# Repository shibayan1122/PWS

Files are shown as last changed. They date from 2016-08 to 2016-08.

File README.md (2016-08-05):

# PWS(Personal Wireless Studio)

---
Maker Faire Tokyo 2016 <http://makezine.jp/event/mft2016/> のヤマハ(株)ブースにて展示を行った、ギター向けIoTデバイス(PWS: Personal Wireless Studio)のハードウェア開発資料・ソフトウェア一式を公開しています。  
PWS の制作方法に関しては、Fabble のプロジェクトページ <http://fabble.cc/yamahafsm/craft-iot-guitar> をご参照下さい。

## ディレクトリ
### hardware
パネル基板の設計図、部品表などを公開しています。

### software
PWS を動作させるのに必要なソフトウェア一式を公開しています。

## 著作権とライセンス
**Copyright (c) 2016 Yamaha Corporation released under the MIT license.**  
このソフトウェアは、MITライセンスのもとで公開しています。詳しくは LICENSE をご参照ください。  
(This software is released under the MIT License, see LICENSE.)

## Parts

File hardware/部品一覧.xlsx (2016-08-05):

■部品一覧 | 最終更新日：2016/08/05
ここでは「PWSを作ろう」で使用している構成部品を紹介しています。「PWSを作ろう」と照らし合わせながらご覧ください。
各部品は、製品例と同じものをそのまま使用していただくことも、 同等の役割ものに変更していただくことも可能です。 必要に応じて、ご自身でご変更ください。
この部品を使用している項 | 部品名称 | 必要個数 | 製品例 | 購入先例 | 備考
ピエゾピックアップを作る | ピエゾ素子（圧電素子） | 1 | THRIVE 圧電型マイクロスピーカーユニット φ26-50u(B) | 千石電商 http://www.sengoku.co.jp/ | ピエゾ素子によっては、信号が弱い場合がありますのでご注意ください。
 | 1芯シールド線 | 適量 |  | 千石電商 http://www.sengoku.co.jp/
 | PHコネクタ 2Pオス | 1 | JST PHR-2 | 千石電商 http://www.sengoku.co.jp/
 | PHコネクタ ハウジング用コンタクト | 2 | JST BPH-002T-P0.5S | 千石電商 http://www.sengoku.co.jp/ | 取り付けにはコンタクト用圧着工具が必要です。
アンプ回路を作る | アンプ回路 | 1 | 高感度マイクアンプキット K-05757 | 秋月電子通商 http://akizukidenshi.com/ | 改造して使用します。改造内容は「アンプ回路を作る」をご参照ください。
 | 抵抗 100kΩ | 1 | チップ抵抗 100kΩ ※チップ抵抗だと実装しやすいです。 | RSコンポーネンツ http://jp.rs-online.com/ | ゲイン調整用
 | 電解コンデンサ 22uF | 1 | 50V22uF | 秋月電子通商 http://akizukidenshi.com/ | DCカット用
 | Φ3.5ステレオイヤフォン端子 | 1 | 3.5mmΦステレオミニプラグMP319 C-05749 | 秋月電子通商 http://akizukidenshi.com/ | アンプ回路音声出力－USBオーディオ変換アダプタマイク入力用
 | PHコネクタ 2Pメス | 1 | JST B2B-PH-K-S(LF) | 千石電商 http://www.sengoku.co.jp/
 | 抵抗 1kΩ | 1 | 1/6W 1kΩ | 秋月電子通商 http://akizukidenshi.com/ | ノイズ対策のフィルタ回路用
 | 積層セラミックコンデンサ 0.1uF | 1 | 50V0.1uF | 秋月電子通商 http://akizukidenshi.com/
 | 電解コンデンサ 100uF | 1 | 25V100uF | 秋月電子通商 http://akizukidenshi.com/
 | 線材 | 適量 |  |  | 細すぎないもの、またはシールド線をお勧めします。
操作表示基板を作る | 抵抗 220Ω | 3 | 1/6W 220Ω | 秋月電子通商 http://akizukidenshi.com/ | Maker Faire Tokyo 2016配布基板は、1/6Wの抵抗の大きさに対応しています。
 | LED 赤 | 1 | LENOO L034MD φ3着色赤色ＬＥＤ | 千石電商 http://www.sengoku.co.jp/ | Maker Faire Tokyo 2016配布基板は、φ3に対応しています。
 | LED 緑 | 1 | LENOO L034GD φ3着色黄色ＬＥＤ | 千石電商 http://www.sengoku.co.jp/
 | LED 黄 | 1 | LENOO L034YD φ3着色緑色ＬＥＤ | 千石電商 http://www.sengoku.co.jp/
 | タクトスイッチ | 7 | タクトスイッチ 各色 例：白 P-03648 | 秋月電子通商 http://akizukidenshi.com/ | Maker Faire Tokyo 2016配布基板は、この秋月のタクトスイッチに対応しています。
 | 線材 | 適量 |  |  | 細すぎないものをお勧めします。
PWSを組み立てる | 外装(箱やケースなど） | 1 | DVD2枚用ダンボール 内寸193×139×31mm | Amazon.co.jp https://www.amazon.co.jp/ | 無線LAN子機を中に納める場合、鉄製の外装は電波に影響が出ますので避けてください。
 | Raspberry Pi Zero | 1 |  | Amazon.co.jp https://www.amazon.co.jp/ | バージョンは、Raspberry Pi Zero V1.3 まで使用可能であることを確認しています。
 | microSD 16G以上 | 1 |  | Amazon.co.jp https://www.amazon.co.jp/
 | バッテリー | 1 | IoT機器対応のモバイルバッテリー cheero CANVAS 3200mAh | アスキーストア http://ascii-store.jp/ | 乾電池は電流が不安定になり、落ちる可能性があります。
 | USB-microUSB変換ケーブル | 1 | パイナップル USBケーブル Aオス-microUSBオス 20cm 左出し用 | あきばお～ http://www.akibaoo.co.jp/ | バッテリー － Raspberry Pi Zero用
 | USBハブ | 1 | iBUFFALO USB2.0ハブ BSH4UMB01BK | Amazon.co.jp https://www.amazon.co.jp/ | ご自身の必要ポート数のものをご用意ください。
 | USBオーディオ変換アダプタ | 1 | Plugable USB オーディオ変換アダプタ USB-AUDIO | Amazon.co.jp https://www.amazon.co.jp/ | Plugable USB-AUDIOは、アンプを内蔵していないためノイズが少ないです。
 | 無線LAN子機 | 1 | PLANEX 無線LAN子機 GW-USECO300A (FFP) | Amazon.co.jp https://www.amazon.co.jp/ | ご自身のWiFi環境に対応したものをご用意ください。
 | USB延長ケーブル | 1 | SSA SU2－AA05R USB(2.0) 延長ケーブル5cm | 千石電商 http://www.sengoku.co.jp/ | USBハブ－USBオーディオ変換アダプタ用
 | 両面テープ、テープなど | 適量

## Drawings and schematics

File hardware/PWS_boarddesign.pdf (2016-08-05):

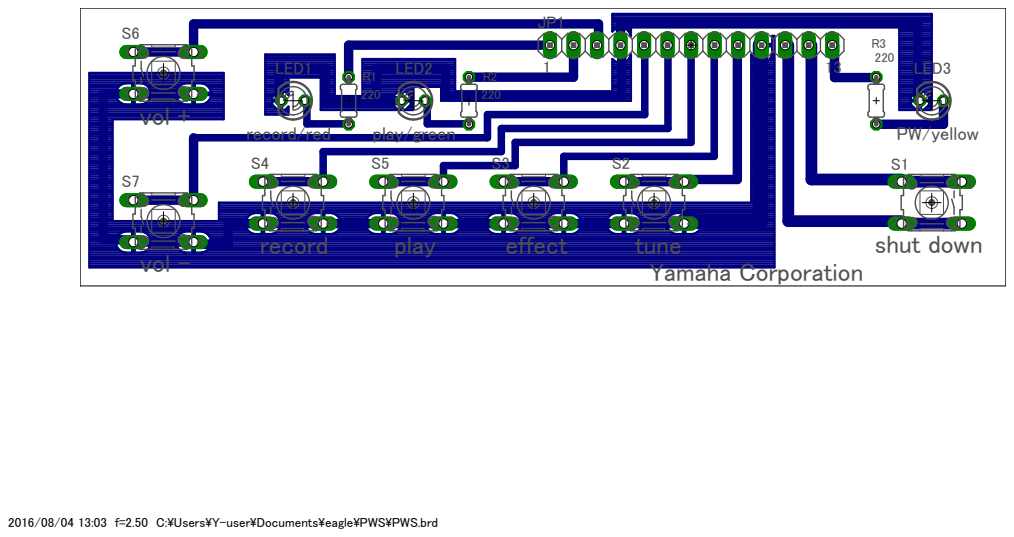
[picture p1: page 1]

2016/08/04 13:03 f=2.50 C:\Users\Y-user\Documents\eagle\PWS\PWS.brd

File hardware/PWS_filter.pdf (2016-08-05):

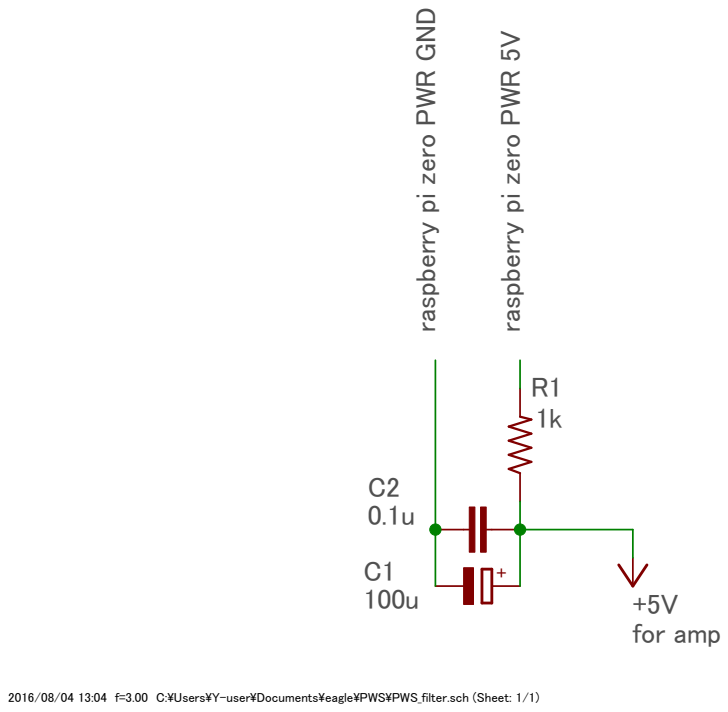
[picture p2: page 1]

2016/08/04 13:04 f=3.00 C:\Users\Y-user\Documents\eagle\PWS\PWS_filter.sch (Sheet: 1/1)

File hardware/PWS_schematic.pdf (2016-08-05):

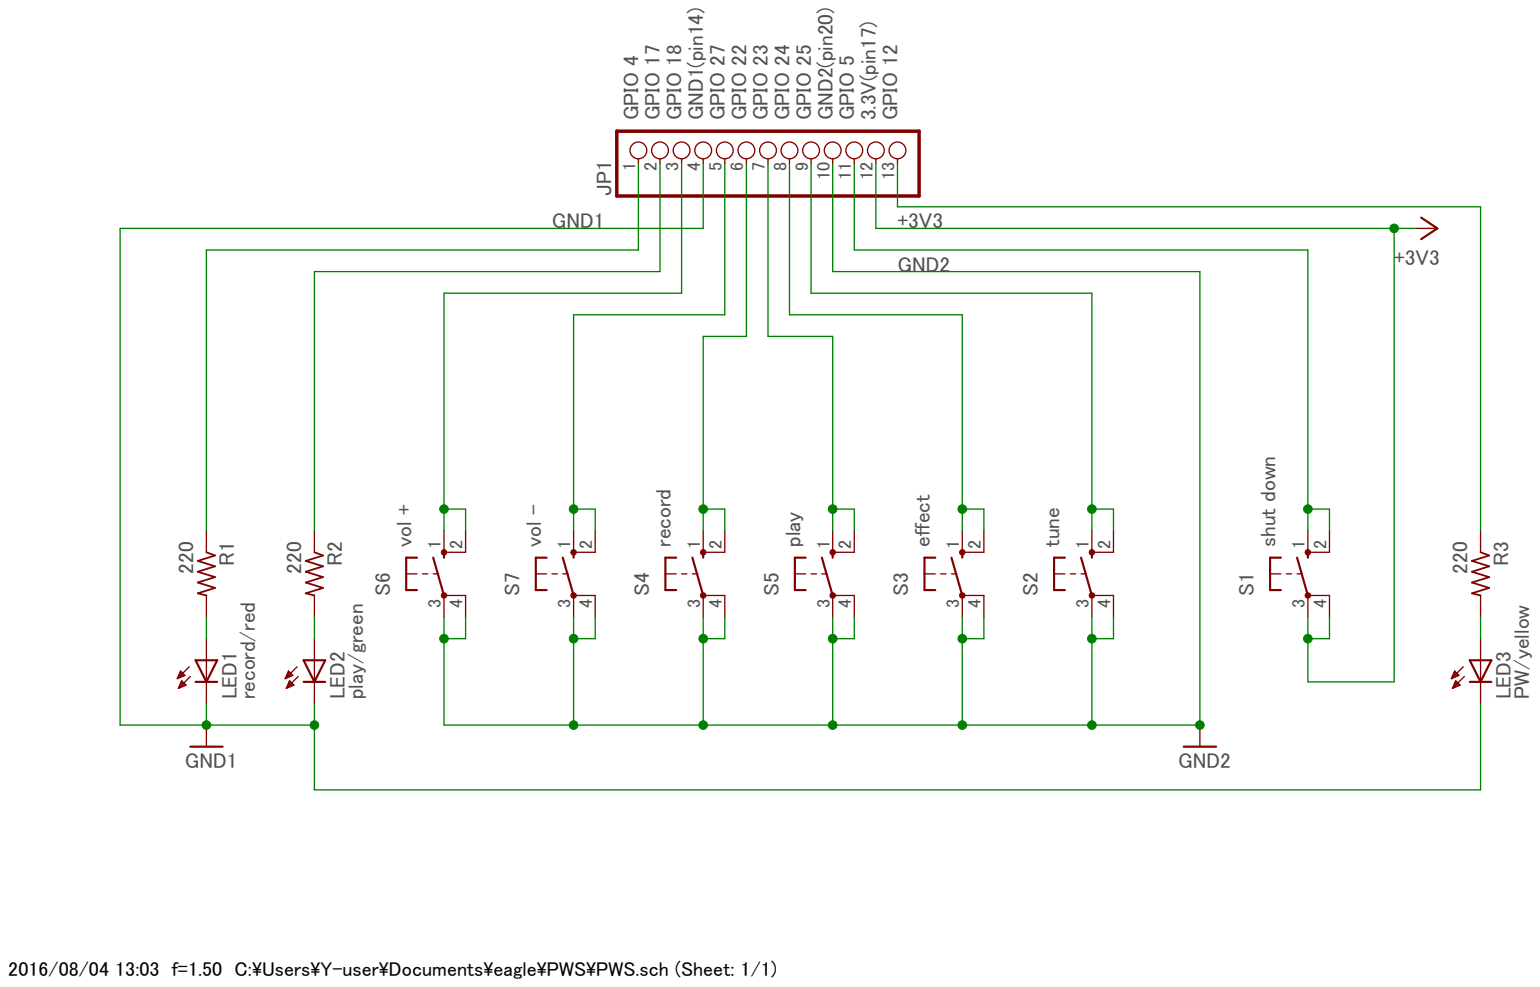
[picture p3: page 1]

2016/08/04 13:03 f=1.50 C:\Users\Y-user\Documents\eagle\PWS\PWS.sch (Sheet: 1/1)

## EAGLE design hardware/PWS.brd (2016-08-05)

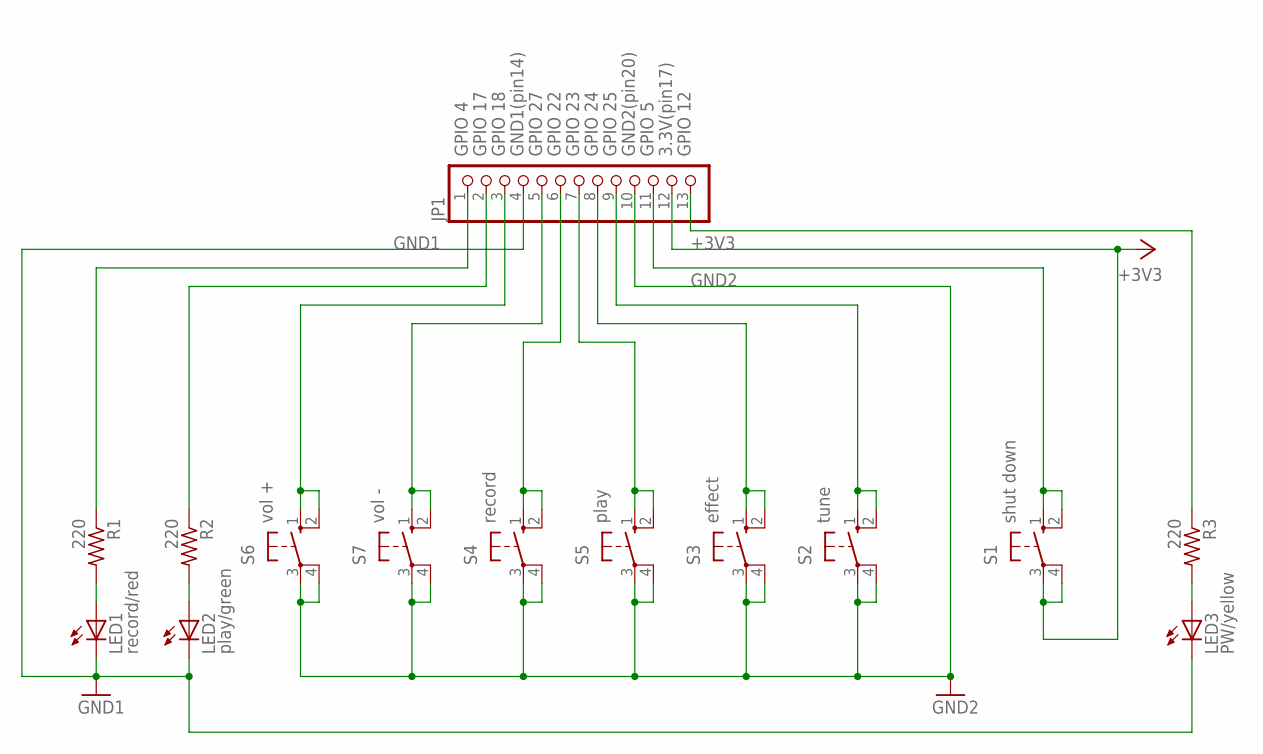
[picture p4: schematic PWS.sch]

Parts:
JP1: PINHD-1X13; 1X13
LED1: record/red; LED3MM
LED2: play/green; LED3MM
LED3: PW/yellow; LED3MM
R1, R2, R3: 220; 0204/5
S1: shut down; B3F-10XX
S2: tune; B3F-10XX
S3: effect; B3F-10XX
S4: record; B3F-10XX
S5: play; B3F-10XX
S6: vol +; B3F-10XX
S7: vol -; B3F-10XX

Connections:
+3V3: JP1.12, S1.3, S1.4 (P1)
GND1: JP1.4, LED1.K (C), LED2.K (C), LED3.K (C)
GND2: JP1.10, S2.3, S2.4 (P1), S3.3, S3.4 (P1), S4.3, S4.4 (P1), S5.3, S5.4 (P1), S6.3, S6.4 (P1), S7.3, S7.4 (P1)
unnamed: LED1.A, R1.2
unnamed: LED2.A, R2.2
unnamed: LED3.A, R3.2
unnamed: JP1.5, S7.1 (S), S7.2 (S1)
unnamed: JP1.3, S6.1 (S), S6.2 (S1)
unnamed: JP1.8, S3.1 (S), S3.2 (S1)
unnamed: JP1.7, S5.1 (S), S5.2 (S1)
unnamed: JP1.9, S2.1 (S), S2.2 (S1)
unnamed: JP1.11, S1.1 (S), S1.2 (S1)
unnamed: JP1.13, R3.1
unnamed: JP1.6, S4.1 (S), S4.2 (S1)
unnamed: JP1.2, R2.1
unnamed: JP1.1, R1.1

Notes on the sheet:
GPIO 4
GPIO 17
GPIO 12
GPIO 5
GPIO 25
GPIO 24
GPIO 22
GPIO 23
GPIO 18
GPIO 27
GND1(pin14)
GND2(pin20)
3.3V(pin17)

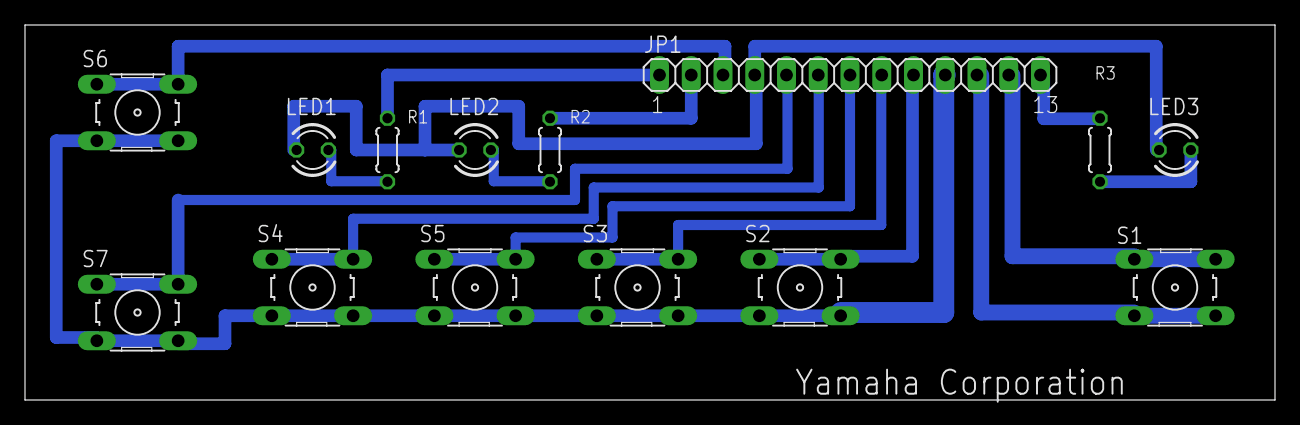
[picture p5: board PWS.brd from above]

Board: 2 copper layers, 100.0 x 30.0 mm, 14 parts (0 on the bottom side), 16 nets.

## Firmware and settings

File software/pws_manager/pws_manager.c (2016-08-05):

///////////////////////////////////////////////////////////
// pws_manager.c
///////////////////////////////////////////////////////////

#include <stdio.h>
#include <stdlib.h>
#include <signal.h>
#include <unistd.h>
#include <string.h>
#include <stdint.h>
#include <pthread.h>
#include <sys/types.h>
#include <sys/socket.h>
#include <sys/un.h>
#include <netinet/in.h>
#include <arpa/inet.h>
#include "pws_manager.h"
#include "pws_osc.h"
#include "pws_gpio.h"
#include "pws_led.h"
#include "pws_debug.h"

//
// ステートマシンの状態
//
typedef enum {
    STATE_INIT = 0              ,   // 初期化中
    STATE_APSET                 ,   // AP設定モード中
    STATE_APSET_WAIT            ,   // AP設定終了待ち
    STATE_PD_WAIT               ,   // PD初期化終了待ち
    STATE_IDLE                  ,   // アイドル
    STATE_REC                   ,   // 録音中
    STATE_PLAY                  ,   // 再生中
    STATE_TUNE                  ,   // チューニング中
    STATE_MAX                       // 最大個数
} STATE;

//
// イベント
//
typedef enum {
    EVT_NONE       = -1         ,   // イベントなし
    EVT_INITIALIZE              ,   // 起動
    EVT_PUSH_AP_SET_BTN         ,   // AP設定ボタン押下
    EVT_RECV_AP_CONFIGURED      ,   // AP設定終了通知
    EVT_RECV_AP_CONFIG_ERROR    ,   // AP設定異常通知
    EVT_RECV_PD_INIT_FINISHED   ,   // PD初期化終了通知
    EVT_RECV_PD_INIT_ERROR      ,   // PD初期化異常通知
    EVT_PUSH_REC_BTN            ,   // 録音ボタン押下
    EVT_RECV_REC_STOPPED        ,   // 録音終了通知
    EVT_PUSH_PLAY_BTN           ,   // 再生ボタン押下
    EVT_RECV_PLAY_STOPPED       ,   // 再生終了通知
    EVT_PUSH_VOL_UP_BTN         ,   // ボリュームアップボタン押下
    EVT_PUSH_VOL_DOWN_BTN       ,   // ボリュームダウンボタン押下
    EVT_PUSH_EFFECT_BTN         ,   // エフェクトボタン押下
    EVT_PUSH_TUNING_BTN         ,   // チューニングボタン押下
    EVT_RECV_TUNING_STOPPED     ,   // チューニング終了通知
    EVT_RECV_TUNING_COND        ,   // チューニング状態通知
    EVT_RECV_UPLOAD_STARTED     ,   // アップロード開始通知
    EVT_RECV_UPLOAD_STOPPED     ,   // アップロード終了通知
    EVT_RECV_DOWNLOAD_STOPPED   ,   // ダウンロード終了通知
    EVT_PUSH_SHUTDOWN_BTN       ,   // シャットダウンボタン押下 
    EVT_MAX                         // イベント最大個数
} EVENT;

//
// マネージャーのコンテキスト（状態管理）
//
static struct {
    int state;
    int event;
} MgrCtx;

//
// 関数のプロトタイプ宣言
//
static int mgrInitialize(int code, void *arg1, void *arg2);
static int mgrApConfigure(int code, void *arg1, void *arg2);
static int mgrApConfigured(int code, void *arg1, void *arg2);
static int mgrApConfigError(int code, void *arg1, void *arg2);
static int mgrPdInitFinished(int code, void *arg1, void *arg2);
static int mgrPdInitError(int code, void *arg1, void *arg2);
static int mgrRecStart(int code, void *arg1, void *arg2);
static int mgrRecStop(int code, void *arg1, void *arg2);
static int mgrRecStopped(int code, void *arg1, void *arg2);
static int mgrPlayStart(int code, void *arg1, void *arg2);
static int mgrPlayStop(int code, void *arg1, void *arg2);
static int mgrPlayStopped(int code, void *arg1, void *arg2);
static int mgrVolumeUp(int code, void *arg1, void *arg2);
static int mgrVolumeDown(int code, void *arg1, void *arg2);
static int mgrEffectChange(int code, void *arg1, void *arg2);
static int mgrTuningStart(int code, void *arg1, void *arg2);
static int mgrTuningStop(int code, void *arg1, void *arg2);
static int mgrTuningStopped(int code, void *arg1, void *arg2);
static int mgrTuningCond(int code, void *arg1, void *arg2);
static int mgrUploadStarted(int code, void *arg1, void *arg2);
static int mgrUploadStopped(int code, void *arg1, void *arg2);
static int mgrDownloadStopped(int code, void *arg1, void *arg2);
static int mgrShutdown(int code, void *arg1, void *arg2);

static int mgrGetEvent(char *buf, int len, OSC_MESSAGE *msg);
static int mgrSendMessageToSndModule(int port, char *msg, char *param);
static int mgrSendMessageToLedController(char *msg);
static void mgrCloseSocket(void);
static void mgrSigHandler(int sig);

#if defined(DEBUG_LOGOUT_STDIO) || defined(DEBUG_LOGOUT_FILE)
static void mgrDebugOut(char *buf, int len);
#endif

//
// 状態遷移テーブル
//
static struct {
    int next;
    int (*func)(int code, void *arg1, void *arg2);
} STATE_TABLE[STATE_MAX][EVT_MAX] = {
    //
    // STATE_INIT：初期化中
    //
    {
        { STATE_PD_WAIT   , mgrInitialize       }, // 起動
        { STATE_APSET     , mgrApConfigure      }, // AP設定ボタン押下
        { STATE_INIT      , NULL                }, // AP設定終了通知
        { STATE_INIT      , NULL                }, // AP設定異常通知
        { STATE_IDLE      , mgrPdInitFinished   }, // PD初期化終了通知
        { STATE_INIT      , mgrPdInitError      }, // PD初期化異常通知
        { STATE_INIT      , NULL                }, // 録音ボタン押下
        { STATE_INIT      , NULL                }, // 録音終了通知
        { STATE_INIT      , NULL                }, // 再生ボタン押下
        { STATE_INIT      , NULL                }, // 再生終了通知
        { STATE_INIT      , NULL                }, // ボリュームアップボタン押下
        { STATE_INIT      , NULL                }, // ボリュームダウンボタン押下
        { STATE_INIT      , NULL                }, // エフェクトボタン押下
        { STATE_INIT      , NULL                }, // チューニングボタン押下
        { STATE_INIT      , NULL                }, // チューニング終了通知
        { STATE_INIT      , NULL                }, // チューニング状態通知
        { STATE_INIT      , NULL                }, // アップロード開始通知
        { STATE_INIT      , NULL                }, // アップロード終了通知
        { STATE_INIT      , NULL                }, // ダウンロード終了通知
        { STATE_INIT      , mgrShutdown         }, // シャットダウンボタン押下
    },

    //
    // STATE_APSET：AP設定モード中
    //
    {
        { STATE_APSET     , NULL                }, // 起動
        { STATE_APSET     , NULL                }, // AP設定ボタン押下
        { STATE_PD_WAIT   , mgrApConfigured     }, // AP設定終了通知
        { STATE_APSET     , mgrApConfigError    }, // AP設定異常通知
        { STATE_APSET_WAIT, mgrPdInitFinished   }, // PD初期化終了通知
        { STATE_APSET     , mgrPdInitError      }, // PD初期化異常通知
        { STATE_APSET     , NULL                }, // 録音ボタン押下
        { STATE_APSET     , NULL                }, // 録音終了通知
        { STATE_APSET     , NULL                }, // 再生ボタン押下
        { STATE_APSET     , NULL                }, // 再生終了通知
        { STATE_APSET     , NULL                }, // ボリュームアップボタン押下
        { STATE_APSET     , NULL                }, // ボリュームダウンボタン押下
        { STATE_APSET     , NULL                }, // エフェクトボタン押下
        { STATE_APSET     , NULL                }, // チューニングボタン押下
        { STATE_APSET     , NULL                }, // チューニング終了通知
        { STATE_APSET     , NULL                }, // チューニング状態通知
        { STATE_APSET     , NULL                }, // アップロード開始通知
        { STATE_APSET     , NULL                }, // アップロード終了通知
        { STATE_APSET     , NULL                }, // ダウンロード終了通知
        { STATE_INIT      , mgrShutdown         }, // シャットダウンボタン押下
    },

    //
    // STATE_APSET_WAIT：AP設定終了待ち
    //
    {
        { STATE_APSET_WAIT, NULL                }, // 起動
        { STATE_APSET_WAIT, NULL                }, // AP設定ボタン押下
        { STATE_IDLE      , mgrApConfigured     }, // AP設定終了通知
        { STATE_APSET_WAIT, mgrApConfigError    }, // AP設定異常通知
        { STATE_APSET_WAIT, NULL                }, // PD初期化終了通知
        { STATE_APSET_WAIT, NULL                }, // PD初期化異常通知
        { STATE_APSET_WAIT, NULL                }, // 録音ボタン押下
        { STATE_APSET_WAIT, NULL                }, // 録音終了通知
        { STATE_APSET_WAIT, NULL                }, // 再生ボタン押下
        { STATE_APSET_WAIT, NULL                }, // 再生終了通知
        { STATE_APSET_WAIT, NULL                }, // ボリュームアップボタン押下
        { STATE_APSET_WAIT, NULL                }, // ボリュームダウンボタン押下
        { STATE_APSET_WAIT, NULL                }, // エフェクトボタン押下
        { STATE_APSET_WAIT, NULL                }, // チューニングボタン押下
        { STATE_APSET_WAIT, NULL                }, // チューニング終了通知
        { STATE_APSET_WAIT, NULL                }, // チューニング状態通知
        { STATE_APSET_WAIT, NULL                }, // アップロード開始通知
        { STATE_APSET_WAIT, NULL                }, // アップロード終了通知
        { STATE_APSET_WAIT, NULL                }, // ダウンロード終了通知
        { STATE_INIT      , mgrShutdown         }, // シャットダウンボタン押下
    },

    //
    // STATE_PD_WAIT：PD初期化終了待ち
    //
    {
        { STATE_PD_WAIT   , NULL                }, // 起動
        { STATE_PD_WAIT   , NULL                }, // AP設定ボタン押下
        { STATE_PD_WAIT   , NULL                }, // AP設定終了通知
        { STATE_PD_WAIT   , NULL                }, // AP設定異常通知
        { STATE_IDLE      , mgrPdInitFinished   }, // PD初期化終了通知
        { STATE_PD_WAIT   , mgrPdInitError      }, // PD初期化異常通知
        { STATE_PD_WAIT   , NULL                }, // 録音ボタン押下
        { STATE_PD_WAIT   , NULL                }, // 録音終了通知
        { STATE_PD_WAIT   , NULL                }, // 再生ボタン押下
        { STATE_PD_WAIT   , NULL                }, // 再生終了通知
        { STATE_PD_WAIT   , NULL                }, // ボリュームアップボタン押下
        { STATE_PD_WAIT   , NULL                }, // ボリュームダウンボタン押下
        { STATE_PD_WAIT   , NULL                }, // エフェクトボタン押下
        { STATE_PD_WAIT   , NULL                }, // チューニングボタン押下
        { STATE_PD_WAIT   , NULL                }, // チューニング終了通知
        { STATE_PD_WAIT   , NULL                }, // チューニング状態通知
        { STATE_PD_WAIT   , NULL                }, // アップロード開始通知
        { STATE_PD_WAIT   , NULL                }, // アップロード終了通知
        { STATE_PD_WAIT   , NULL                }, // ダウンロード終了通知
        { STATE_INIT      , mgrShutdown         }, // シャットダウンボタン押下
    },

    //
    // STATE_IDLE：アイドル中
    //
    {
        { STATE_IDLE      , NULL                }, // 起動
        { STATE_IDLE      , NULL                }, // AP設定ボタン押下
        { STATE_IDLE      , NULL                }, // AP設定終了通知
        { STATE_IDLE      , NULL                }, // AP設定異常通知
        { STATE_IDLE      , NULL                }, // PD初期化終了通知
        { STATE_IDLE      , NULL                }, // PD初期化異常通知
        { STATE_REC       , mgrRecStart         }, // 録音ボタン押下
        { STATE_IDLE      , NULL                }, // 録音終了通知
        { STATE_PLAY      , mgrPlayStart        }, // 再生ボタン押下
        { STATE_IDLE      , NULL                }, // 再生終了通知
        { STATE_IDLE      , mgrVolumeUp         }, // ボリュームアップボタン押下
        { STATE_IDLE      , mgrVolumeDown       }, // ボリュームダウンボタン押下
        { STATE_IDLE      , mgrEffectChange     }, // エフェクトボタン押下
        { STATE_TUNE      , mgrTuningStart      }, // チューニングボタン押下
        { STATE_IDLE      , NULL                }, // チューニング終了通知
        { STATE_IDLE      , NULL                }, // チューニング状態通知
        { STATE_IDLE      , mgrUploadStarted    }, // アップロード開始通知
        { STATE_IDLE      , mgrUploadStopped    }, // アップロード終了通知
        { STATE_IDLE      , mgrDownloadStopped  }, // ダウンロード終了通知
        { STATE_INIT      , mgrShutdown         }, // シャットダウンボタン押下
    },

    //
    // STATE_REC：録音中
    //
    {
        { STATE_REC       , NULL                }, // 起動
        { STATE_REC       , NULL                }, // AP設定ボタン押下
        { STATE_REC       , NULL                }, // AP設定終了通知
        { STATE_REC       , NULL                }, // AP設定異常通知
        { STATE_REC       , NULL                }, // PD初期化終了通知
        { STATE_REC       , NULL                }, // PD初期化異常通知
        { STATE_REC       , mgrRecStop          }, // 録音ボタン押下
        { STATE_IDLE      , mgrRecStopped       }, // 録音終了通知
        { STATE_REC       , NULL                }, // 再生ボタン押下
        { STATE_REC       , NULL                }, // 再生終了通知
        { STATE_REC       , mgrVolumeUp         }, // ボリュームアップボタン押下
        { STATE_REC       , mgrVolumeDown       }, // ボリュームダウンボタン押下
        { STATE_REC       , mgrEffectChange     }, // エフェクトボタン押下
        { STATE_REC       , NULL                }, // チューニングボタン押下
        { STATE_REC       , NULL                }, // チューニング終了通知
        { STATE_REC       , NULL                }, // チューニング状態通知
        { STATE_REC       , mgrUploadStarted    }, // アップロード開始通知
        { STATE_REC       , mgrUploadStopped    }, // アップロード終了通知
        { STATE_REC       , mgrDownloadStopped  }, // ダウンロード終了通知
        { STATE_INIT      , mgrShutdown         }, // シャットダウンボタン押下
    },

    //
    // STATE_PLAY：再生中
    //
    {
        { STATE_PLAY      , NULL                }, // 起動
        { STATE_PLAY      , NULL                }, // AP設定ボタン押下
        { STATE_PLAY      , NULL                }, // AP設定終了通知
        { STATE_PLAY      , NULL                }, // AP設定異常通知
        { STATE_PLAY      , NULL                }, // PD初期化終了通知
        { STATE_PLAY      , NULL                }, // PD初期化異常通知
        { STATE_PLAY      , NULL                }, // 録音ボタン押下
        { STATE_PLAY      , NULL                }, // 録音終了通知
        { STATE_PLAY      , mgrPlayStop         }, // 再生ボタン押下
        { STATE_IDLE      , mgrPlayStopped      }, // 再生終了通知
        { STATE_PLAY      , mgrVolumeUp         }, // ボリュームアップボタン押下
        { STATE_PLAY      , mgrVolumeDown       }, // ボリュームダウンボタン押下
        { STATE_PLAY      , mgrEffectChange     }, // エフェクトボタン押下
        { STATE_PLAY      , NULL                }, // チューニングボタン押下
        { STATE_PLAY      , NULL                }, // チューニング終了通知
        { STATE_PLAY      , NULL                }, // チューニング状態通知
        { STATE_PLAY      , mgrUploadStarted    }, // アップロード開始通知
        { STATE_PLAY      , mgrUploadStopped    }, // アップロード終了通知
        { STATE_PLAY      , mgrDownloadStopped  }, // ダウンロード終了通知
        { STATE_INIT      , mgrShutdown         }, // シャットダウンボタン押下
    },

    //
    // STATE_TUNE：チューニング中
    //
    {
        { STATE_TUNE      , NULL                }, // 起動
        { STATE_TUNE      , NULL                }, // AP設定ボタン押下
        { STATE_TUNE      , NULL                }, // AP設定終了通知
        { STATE_TUNE      , NULL                }, // AP設定異常通知
        { STATE_TUNE      , NULL                }, // PD初期化終了通知
        { STATE_TUNE      , NULL                }, // PD初期化異常通知
        { STATE_TUNE      , NULL                }, // 録音ボタン押下
        { STATE_TUNE      , NULL                }, // 録音終了通知
        { STATE_TUNE      , NULL                }, // 再生ボタン押下
        { STATE_TUNE      , NULL                }, // 再生終了通知
        { STATE_TUNE      , mgrVolumeUp         }, // ボリュームアップボタン押下
        { STATE_TUNE      , mgrVolumeDown       }, // ボリュームダウンボタン押下
        { STATE_TUNE      , mgrEffectChange     }, // エフェクトボタン押下
        { STATE_TUNE      , mgrTuningStop       }, // チューニングボタン押下
        { STATE_IDLE      , mgrTuningStopped    }, // チューニング終了通知
        { STATE_TUNE      , mgrTuningCond       }, // チューニング状態通知
        { STATE_TUNE      , mgrUploadStarted    }, // アップロード開始通知
        { STATE_TUNE      , mgrUploadStopped    }, // アップロード終了通知
        { STATE_TUNE      , mgrDownloadStopped  }, // ダウンロード終了通知
        { STATE_INIT      , mgrShutdown         }, // シャットダウンボタン押下
    },
};

#if defined(DEBUG_LOGOUT_STDIO) || defined(DEBUG_LOGOUT_FILE)
//
// ステート文字列
//
static char *strState[] = {
    "初期化中",
    "AP設定モード中",
    "AP設定終了待ち",
    "PD初期化終了待ち",
    "アイドル",
    "録音中",
    "再生中",
    "チューニング中",
};

//
// イベント文字列
//
static char *strEvt[] = {
    "起動",
    "AP設定ボタン押下",
    "AP設定終了通知",
    "AP設定異常通知",
    "PD初期化終了通知",
    "PD初期化異常通知",
    "録音ボタン押下",
    "録音終了通知",
    "再生ボタン押下",
    "再生終了通知",
    "ボリュームアップボタン押下",
    "ボリュームダウンボタン押下",
    "エフェクトボタン押下",
    "チューニングボタン押下",
    "チューニング終了通知",
    "チューニング状態通知",
    "アップロード開始通知",
    "アップロード終了通知",
    "ダウンロード終了通知",
    "シャットダウンボタン押下 ",
};
#endif

static int sock        = -1;
static int mainFinish  =  0;
static pthread_mutex_t mainMutex = PTHREAD_MUTEX_INITIALIZER;

int main(void)
{
    int rc, n, evt, next, ret, loop;
    char buf[RECV_BUF_SIZE];
    struct sockaddr_in addr;
    int (*func)(int code, void *arg1, void *arg2);
    OSC_MESSAGE oscMsg;

    PWS_DEBUG("START\n");

    // マネージャーのコンテキスト初期化
    memset(&MgrCtx, 0, sizeof(MgrCtx));

    // GPIO初期化
    gpioInitialize();

    // シグナルの設定
    signal(SIGTERM, mgrSigHandler);
    signal(SIGINT , mgrSigHandler);
    signal(SIGKILL, mgrSigHandler);
 
    // ソケット作成
    sock = socket(AF_INET, SOCK_DGRAM, 0);
    if (sock == -1) {
        PWS_DEBUG("Socket Error\n");
        gpioFinish();
        return 1;
    }
    PWS_DEBUG("sock    %d\n", sock);

    memset(&addr, 0, sizeof(addr));
    addr.sin_family      = AF_INET;
    addr.sin_addr.s_addr = INADDR_ANY;
    addr.sin_port        = htons(PWS_PORT_MANAGER);

    rc = bind(sock, (struct sockaddr *)&addr, sizeof(addr));
    if (rc == -1) {
        gpioFinish();
        close(sock);
        sock = -1;
        PWS_DEBUG("Bind Error\n");
        return 2;
    }

    // 起動モードの判定
    gpioCheckApMode();

    loop = 1;
    while (loop) {
        memset(&oscMsg, 0, sizeof(oscMsg));
        memset(buf, 0, sizeof(buf));
        n = recv(sock, buf, sizeof(buf) - 1, 0);
        if (n < 0) {
            PWS_DEBUG("ERROR: recv\n");
            break;
        }
#if defined(DEBUG_LOGOUT_STDIO) || defined(DEBUG_LOGOUT_FILE)
        mgrDebugOut(buf, n);
#endif
        evt = mgrGetEvent(buf, n, &oscMsg);
#if defined(DEBUG_LOGOUT_STDIO) || defined(DEBUG_LOGOUT_FILE)
        if (evt >= 0) {
            PWS_DEBUG("evt=%2d [%s]\n", evt, strEvt[evt]);
        }
        else {
            PWS_DEBUG("evt=%2d [（イベント無し）]\n", evt);
        }
#endif
        if (evt >= 0) {
            next = STATE_TABLE[MgrCtx.state][evt].next;
            func = STATE_TABLE[MgrCtx.state][evt].func;
            if (func != NULL) {
                ret = func(oscMsg.data[0].u.i, oscMsg.data[1].u.s, oscMsg.data[2].u.s);
                if (ret < 0) {
                    // func error !!
                    PWS_DEBUG("ERROR: func()[%s][%s]\n", strState[MgrCtx.state], strEvt[evt]);
                }
            }
            PWS_DEBUG("state  [%s] --> [%s]\n", strState[MgrCtx.state], strState[next]);
            MgrCtx.state = next;
        }

        pthread_mutex_lock(&mainMutex);
        if (mainFinish == 1) {
            loop = 0;
        }
        pthread_mutex_unlock(&mainMutex);
    }

    gpioFinish();

    mgrCloseSocket();

    return 0;
}


//
// アクション関数
//


// 初期化
static int  mgrInitialize(int code, void *arg1, void *arg2)
{
    PWS_DEBUG("action: %s\n", __func__);

    // LED 設定（黄色点灯）
    mgrSendMessageToLedController(MSG_LED_RED_OFF);
    mgrSendMessageToLedController(MSG_LED_GREEN_OFF);
    mgrSendMessageToLedController(MSG_LED_YELLOW_BLINK);

    return 0;
}

// AP設定開始
static int mgrApConfigure(int code, void *arg1, void *arg2)
{
    static const char *cmd = PWS_CMD_AP_CONFIG;
        
    PWS_DEBUG("action: %s\n", __func__);
    
    // LED 設定（緑色点滅）
    mgrSendMessageToLedController(MSG_LED_RED_OFF);
    mgrSendMessageToLedController(MSG_LED_GREEN_BLINK);
    mgrSendMessageToLedController(MSG_LED_YELLOW_OFF);

    system(cmd);

    return 0;
}

// AP設定終了通知受信
static int mgrApConfigured(int code, void *arg1, void *arg2)
{
    static const char *cmd = PWS_CMD_WEB_RESTART;

	PWS_DEBUG("action: %s\n", __func__);

    mgrSendMessageToLedController(MSG_LED_GREEN_OFF);
    switch(MgrCtx.state) {
    case STATE_APSET:
        // LED 設定（黄色点滅）
        mgrSendMessageToLedController(MSG_LED_YELLOW_BLINK);
        break;
    case STATE_APSET_WAIT:
        // LED 設定（黄色点灯）
        mgrSendMessageToLedController(MSG_LED_YELLOW_ON);
        // WEBサーバー再起動
	    system(cmd);
        break;
    default:
        break;
    }

    return 0;
}

// AP設定異常通知
static int mgrApConfigError(int code, void *arg1, void *arg2)
{
    PWS_DEBUG("action: %s\n", __func__);

    if (code < -1) {
        switch(MgrCtx.state) {
        case STATE_APSET:
	        // LED 設定（黄色早点滅）
            mgrSendMessageToLedController(MSG_LED_YELLOW_BLINK_FAST);
            break;
        case STATE_APSET_WAIT:
	        // LED 設定（黄色早点滅）
            mgrSendMessageToLedController(MSG_LED_YELLOW_BLINK_FAST);
            break;
        default:
            break;
        }
    }

    return 0;
}

// PD初期化終了通知
static int mgrPdInitFinished(int code, void *arg1, void *arg2)
{
    PWS_DEBUG("action: %s\n", __func__);

    switch(MgrCtx.state) {
    case STATE_APSET:
        break;
    case STATE_PD_WAIT:
        // LED 設定（黄色点灯）
        mgrSendMessageToLedController(MSG_LED_YELLOW_ON);
        break;
    default:
        break;
    }

    return 0;
}

// PD初期化異常通知
static int mgrPdInitError(int code, void *arg1, void *arg2)
{
    PWS_DEBUG("action: %s\n", __func__);

    switch(MgrCtx.state) {
    case STATE_APSET:
		// LED 設定（黄色早点滅）
        mgrSendMessageToLedController(MSG_LED_YELLOW_BLINK_FAST);
        break;
    case STATE_PD_WAIT:
		// LED 設定（黄色早点滅）
        mgrSendMessageToLedController(MSG_LED_YELLOW_BLINK_FAST);
        break;
    default:
        break;
    }

    return 0;
}

// 録音開始
static int  mgrRecStart(int code, void *arg1, void *arg2)
{
    PWS_DEBUG("action: %s\n", __func__);

    // LED 設定（赤色点灯）
    mgrSendMessageToLedController(MSG_LED_RED_ON);
    // LED 設定（緑色消灯）
    mgrSendMessageToLedController(MSG_LED_GREEN_OFF);
    // LED 設定（黄色点灯）
    mgrSendMessageToLedController(MSG_LED_YELLOW_ON);

    mgrSendMessageToSndModule(PWS_PORT_RECORDER, MSG_REC_START, NULL);
    
    return 0;
}

// 録音終了
static int  mgrRecStop(int code, void *arg1, void *arg2)
{
    PWS_DEBUG("action: %s\n", __func__);

    mgrSendMessageToSndModule(PWS_PORT_RECORDER, MSG_REC_STOP, NULL);

    return 0;
}

// 録音終了通知受信
static int  mgrRecStopped(int code, void *arg1, void *arg2)
{
    PWS_DEBUG("action: %s\n", __func__);

    // LED 設定（赤色消灯）
    mgrSendMessageToLedController(MSG_LED_RED_OFF);
    if (code == 0) {
        mgrSendMessageToSndModule(PWS_PORT_FILE_UPLOADER, MSG_UPLOAD_START, arg1);
    }
    else {
		// LED 設定（黄色早点滅）
        mgrSendMessageToLedController(MSG_LED_YELLOW_BLINK_FAST);
    }

    return 0;
}
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

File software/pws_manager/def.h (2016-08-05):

///////////////////////////////////////////////////////////
//  def.h
///////////////////////////////////////////////////////////
#ifndef __DEF_H__
#define __DEF_H__

// 受信バッファーサイズ
#define RECV_BUF_SIZE               (1024)
#define SEND_BUF_SIZE               (1024)

// コマンド
#define PWS_CMD_AP_CONFIG           "/usr/bin/python /pws/py/ap_conf.py &"
#define PWS_CMD_WEB_RESTART         "/bin/systemctl restart pws-webserver"
#define PWS_CMD_SHUTDOWN            "/sbin/shutdown now -h"

//
// ポート番号定義
//                                            (モジュール名)       (ポート番号)
#define PWS_PORT_MANAGER            (8001)  // PWS Controller       8001
#define PWS_PORT_RECORDER           (8002)  // Recorder             8002
#define PWS_PORT_PLAYER             (8003)  // Player               8003
#define PWS_PORT_TUNER              (8004)  // Tuner                8004
#define PWS_PORT_EFFECT_CONTROLLER  (8005)  // Effect Controller    8005
#define PWS_PORT_AUDIO_OUT          (8006)  // Audio Out            8006
#define PWS_PORT_FILE_UPLOADER      (8100)  // File Uploader        8100
#define PWS_PORT_FILE_DOWNLOADER    (8101)  // File Downloader      8101
#define PWS_PORT_AP_CONFIGURATOR    (8200)  // AP Configurator      8200

//
// 通信メッセージ
//
#define MSG_PD_INIT_FINISHED    "/pd_initializer/initialize/finished"   // PD初期化終了土        (Pd Initializer    →  PWS Controller   ）
#define MSG_REC_START           "/recorder/record/start"                // 録音開始要求         （PWS Controller    →  Recorder         ）
#define MSG_REC_STOP            "/recorder/record/stop"                 // 録音終了要求         （PWS Controller    →  Recorder         ）
#define MSG_REC_STARTED         "/recorder/record/started"              // 録音開始通知         （Recorder          →  PWS Controller   ）
#define MSG_REC_STOPPED         "/recorder/record/stopped"              // 録音終了通知         （Recorder          →  PWS Controller   ）
#define MSG_PLAY_START          "/player/playback/start"                // 再生開始要求         （PWS Controller    →  Player           ）
#define MSG_PLAY_STOP           "/player/playback/stop"                 // 再生終了要求         （PWS Controller    →  Player           ）
#define MSG_PLAY_STARTED        "/player/playback/started"              // 再生開始通知         （Player            →  PWS Controller   ）
#define MSG_PLAY_STOPPED        "/player/playback/stopped"              // 再生終了通知         （Player            →  PWS Controller   ）
#define MSG_TUNING_START        "/tuner/tune/start"                     // チューニング開始要求 （PWS Controller    →  Tuner            ）
#define MSG_TUNING_STOP         "/tuner/tune/stop"                      // チューニング終了要求 （PWS Controller    →  Tuner            ）
#define MSG_TUNING_STARTED      "/tuner/tune/started"                   // チューニング開始通知 （Tuner             →  PWS Controller   ）
#define MSG_TUNING_STOPPED      "/tuner/tune/stopped"                   // チューニング終了通知 （Tuner             →  PWS Controller   ）
#define MSG_TUNING_COND         "/tuner/tune/cond"                      // チューニング状態通知 （Tuner             →  PWS Controller   ）
#define MSG_EFFECT_CHANGE       "/effector/effect/toggle"               // エフェクト変更要求   （PWS Controller    →  Effect Controller）
#define MSG_VOL_UP              "/audio_out/volume/up"                  // ボリュームアップ要求 （PWS Controller    →  Audio Out        ）
#define MSG_VOL_DOWN            "/audio_out/volume/down"                // ボリュームダウン要求 （PWS Controller    →  Audio Out        ）
#define MSG_UPLOAD_START        "/uploader/upload/start"                // アップロード開始要求 （PWS Controller    →  File Uploader    ）
#define MSG_UPLOAD_STARTED      "/uploader/upload/started"              // アップロード開始通知 （File Uploader     →  PWS Controller   ）
#define MSG_UPLOAD_STOP         "/uploader/upload/stop"                 // アップロード終了要求 （PWS Controller    →  File Uploader    ）
#define MSG_UPLOAD_STOPPED      "/uploader/upload/stopped"              // アップロード終了通知 （File Uploader     →  PWS Controller   ）
#define MSG_DOWNLOAD_START      "/downloader/download/start"            // ダウンロード開始要求 （PWS Controller    →  File Downloader  ）
#define MSG_DOWNLOAD_STOP       "/downloader/download/started"          // ダウンロード開始通知 （File Downloader   →  PWS Controller   ）
#define MSG_DOWNLOAD_STOPPED    "/downloader/download/stopped"          // ダウンロード終了通知 （File Downloader   →  PWS Controller   ）
#define MSG_AP_CONFIGURED       "/ap_configurator/configure/configured" // AP設定終了通知       （AP Configurator   →  PWS Controller   ）
#define MSG_SYSTEM_LED_SET      "/system/led/set"                       // システムLED操作      （anyone            →  PWS Controller   ）

#endif  // __DEF_H__

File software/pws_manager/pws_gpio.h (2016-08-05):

///////////////////////////////////////////////////////////
// pws_gpio.h
///////////////////////////////////////////////////////////
#ifndef __PWS_GPIO_H__
#define __PWS_GPIO_H__

//
// wiringPi用ピン番号表
//
//  +-----+-----+---------+------+---+-Pi Zero--+---+------+---------+-----+-----+
//  | BCM | wPi |   Name  | Mode | V | Physical | V | Mode | Name    | wPi | BCM |
//  +-----+-----+---------+------+---+----++----+---+------+---------+-----+-----+
//  |     |     |    3.3v |      |   |  1 || 2  |   |      | 5v      |     |     |
//  |   2 |   8 |   SDA.1 |   IN | 1 |  3 || 4  |   |      | 5V      |     |     |
//  |   3 |   9 |   SCL.1 |   IN | 1 |  5 || 6  |   |      | 0v      |     |     |
//  |   4 |   7 | GPIO. 7 |   IN | 1 |  7 || 8  | 1 | ALT0 | TxD     | 15  | 14  |
//  |     |     |      0v |      |   |  9 || 10 | 1 | ALT0 | RxD     | 16  | 15  |
//  |  17 |   0 | GPIO. 0 |   IN | 0 | 11 || 12 | 0 | IN   | GPIO. 1 | 1   | 18  |
//  |  27 |   2 | GPIO. 2 |   IN | 0 | 13 || 14 |   |      | 0v      |     |     |
//  |  22 |   3 | GPIO. 3 |   IN | 0 | 15 || 16 | 0 | IN   | GPIO. 4 | 4   | 23  |
//  |     |     |    3.3v |      |   | 17 || 18 | 0 | IN   | GPIO. 5 | 5   | 24  |
//  |  10 |  12 |    MOSI |   IN | 0 | 19 || 20 |   |      | 0v      |     |     |
//  |   9 |  13 |    MISO |   IN | 0 | 21 || 22 | 0 | IN   | GPIO. 6 | 6   | 25  |
//  |  11 |  14 |    SCLK |   IN | 0 | 23 || 24 | 1 | IN   | CE0     | 10  | 8   |
//  |     |     |      0v |      |   | 25 || 26 | 1 | IN   | CE1     | 11  | 7   |
//  |   0 |  30 |   SDA.0 |   IN | 1 | 27 || 28 | 1 | IN   | SCL.0   | 31  | 1   |
//  |   5 |  21 | GPIO.21 |   IN | 1 | 29 || 30 |   |      | 0v      |     |     |
//  |   6 |  22 | GPIO.22 |   IN | 1 | 31 || 32 | 0 | IN   | GPIO.26 | 26  | 12  |
//  |  13 |  23 | GPIO.23 |   IN | 0 | 33 || 34 |   |      | 0v      |     |     |
//  |  19 |  24 | GPIO.24 |   IN | 0 | 35 || 36 | 0 | IN   | GPIO.27 | 27  | 16  |
//  |  26 |  25 | GPIO.25 |   IN | 0 | 37 || 38 | 0 | IN   | GPIO.28 | 28  | 20  |
//  |     |     |      0v |      |   | 39 || 40 | 0 | IN   | GPIO.29 | 29  | 21  |
//  +-----+-----+---------+------+---+----++----+---+------+---------+-----+-----+
//  | BCM | wPi |   Name  | Mode | V | Physical | V | Mode | Name    | wPi | BCM |
//  +-----+-----+---------+------+---+-Pi Zero--+---+------+---------+-----+-----+

// LEDのwPiピン番号
// ------------------------------------
// 名称     GPIOピン番号    wPiピン番号  
// LED1     4               7           赤色
// LED2     17              0           緑色
// LED3     12              26          黄色／起動状態を示す（起動している間ずっと光る）

#define PIN_LED_RED         (7)         // 赤色 LED
#define PIN_LED_GREEN       (0)         // 緑色 LED
#define PIN_LED_YELLOW      (26)        // 黄色 LED

// ボタンのwPiピン番号
// ------------------------------------
// 名称     GPIOピン番号    wPiピン番号
// ボタン1  5               21
// ボタン2  25              6
// ボタン3  24              5
// ボタン4  22              3
// ボタン5  23              4
// ボタン6  18              1
// ボタン7  27              2
#define PIN_BTN_1           (21)        // ボタン1
#define PIN_BTN_2           (6)         // ボタン2
#define PIN_BTN_3           (5)         // ボタン3
#define PIN_BTN_4           (3)         // ボタン4
#define PIN_BTN_5           (4)         // ボタン5
#define PIN_BTN_6           (1)         // ボタン6
#define PIN_BTN_7           (2)         // ボタン7

// ピンの値
#define PIN_VAL_ON          (1)
#define PIN_VAL_OFF         (0)


// スイッチ長押し時間（ミリ秒）
#define LONG_PUSH_TIME      (2000.0)

extern int gpioInitialize(void);
extern void gpioCheckApMode(void);
extern int gpioRead(int pin);
extern void gpioWrite(int pin, int val);
extern void gpioFinish(void);

#endif // __PWS_GPIO_H__
